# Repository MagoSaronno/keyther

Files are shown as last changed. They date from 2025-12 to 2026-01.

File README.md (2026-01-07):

# Keyther Keyboard
The Keyther Keyboard represents an attempt at perfecting the already great [Cantor Classic](https://github.com/diepala/cantor "The original project").  The name comes from the combination of the substantives **Keyboard** and **Ethernet**, due to the use of an RJ45 socket. 

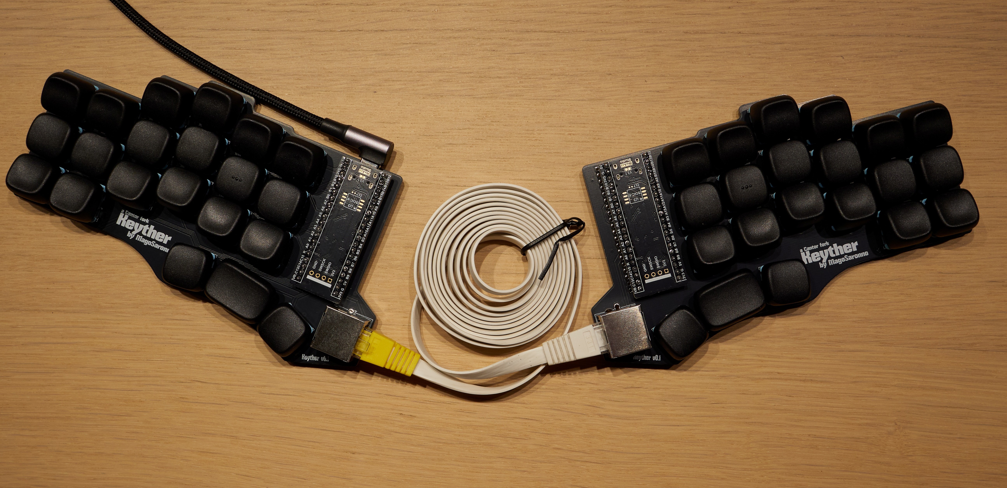
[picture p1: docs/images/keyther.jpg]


*Special thanks to both [diepala](https://github.com/diepala "The Cantor Keyboard creator") and [daprice](https://github.com/daprice "The creator of the footprints libraries") for having paved the way for the creation of the Keyther Keyboard.*

### What changes from Cantor

1. The TRRS socket is replaced with the more secure RJ45 (Ethernet) to avoid *critical* integrity issues caused by accidental disconnection or hot-plugging.  Indeed, the Keyther Keyboard supports hot-plugging, as shown in this video:
 <p align="center"> 
   <a href="https://youtu.be/JiO30BsTjEQ">
    Watch the video
  </a>
</p>

2. The design introduces **hot-swappable** Kailh Choc **sockets** and **handedness by pin** (through the addition of a 10k resistor and an added line in the config.h file)
You won't have to desolder all 42 switches to change them and you will be able to connect the keyboard even through the right half.

3. The horizontal space between switches has been *increased*, accommodating larger hands **without** additional modifications to the overall PCB size (expept the space for the RJ45 socket).

### What does not change

The keyther keyboard keeps (*for the most part*) the original concepts that were at the origin of Cantor, which are the diodeless design and the use of an invertible PCB design, to ultimately avoid cuttable costs.

### Why RJ45 instead of USB-C or magnetic pogo pin sockets?

The main reasons to use RJ45 sockets are their easy soldering, their overall diffusion, and the widespread presence of premade cables of different kinds, like coiled, straight, and flat.

Additionally, the number of pins present on the socket allows the possible addition of two optional communication lines between PCBs for whatever use (namely pins 1 and 5).

# Be Aware
The Keyther Keyboard is designed to be used with ***STRAIGHT-THROUGH CABLES***, not the crossover ones.

***Always check the cable type before connecting the two halves***.

## Disclaimer
All the designs and files are provided "AS IS" without any warranty or support.

## Links Index

[Ordering Guide](docs/Ordering_Guide.md)

[Assembly Guide](docs/Assembling_Guide.md)

[Firmware Guide](https://qmk.fm/guide "The default guide for the Cantor Keyboard")

## Quick Guide

### Bill of Materials (BOM)
The required components needed to assemble the keyboard are the following:
| N. | Item | Notes |
|----|---|---|
| 2  | PCB board | |
| 2  | STM32F401CC BlackPill microcontrollers | *on [AliExpress](https://it.aliexpress.com/item/1005005953179540.html?)* |
| 4  | 20 pin stripes | *usually included with the Blackpill* |
| 42 | Kailh Choc ***v1*** switches | *namely the Kailh PG1350* |
| 42 | Kailh Choc hot-swap sockets | |
| 42 | Kailh Choc ***v1*** compatible keycaps | |
| 2  | RJ45 sockets (RJHSE type, e.g., the [RJHSE-XM80](https://docs.rs-online.com/b456/A700000007566767.pdf "The technical drawing of the socket"))| *on [AliExpress](https://it.aliexpress.com/item/1005007661898327.html?)* |
| 1  | Straight-through Ethernet cable | *flat ones seem to be more flexible and less annoying when using the keyboard* |
| 1  | USB-C cable compatible with your computer | |

### Ordering the PCB
To order the PCB, you will need the Gerber files present in the [Release section](https://github.com/MagoSaronno/keyther/releases). Then, you can either compare the prices on [PCBShopper](https://pcbshopper.com/ "A price comparison site for printed PCBs") by choosing a dimension of 150x90mm or upload them directly to the PCB manufacturer's website of choice.

You can refer to the [Ordering Tutorial](docs/Ordering_Guide.md) page which provides a step-by-step guide on the ordering procedure.

> I personally prototyped my PCBs using JLCPCB, primarily due to lower prices. However, these may vary depending on your customs policies and regional shipping rates.

### Firmware
> It is preferable to flash and check the microcontroller for defects before assembling the keyboard.

The Keyther Keyboard uses the [QMK Firmware](https://qmk.fm/), specifically the same as the Cantor Keyboard. You can easily follow the [guide](https://qmk.fm/guide "The default guide for the Cantor Keyboard") on the QMK website to *customise* and *compile* the firmware.

To add **language-specific characters** (such as *accented* or *umlaut* vowels) you can follow this [additional guide](Language-Specific_Keymap.md).

Unfortunately, at this time, to add the handedness feature to your keyboard you will need to use the [QMK source](https://docs.qmk.fm/newbs "The guide to use the source"), and, before compiling, add to the cantor's config.h file the line:

`#define SPLIT_HAND_PIN B12`

### Enter Bootloader Mode
To flash the firmware onto the microcontroller you will need to set it in bootloader mode first:
- Press and hold the BOOT0 button.
- Press and release the NRST button.
- Release the BOOT0 button.

Now you will be able to flash the firmware and check if the microcontroller works properly.

> Once the first flash has been done successfully you will be able to enter bootloader mode just by plugging in one half of the keyboard **while** holding down the top-left or top-right (*whether it is the left or right keyboard half*).

### Assemble the keyboard
To assemble your Keyther Keyboard you will need a soldering iron and tin of your choice. You can also follow the [Assembly Guide](docs/Assembling_Guide.md).

### Printing the Keyther cases
To 3D print the cases to protect the bottom of your keyboard halves you will need to download the *.stl* files present in the [case folder](https://github.com/MagoSaronno/keyther/tree/main/case) of this repository and slice them with the appropriate software.

In case you wish to modify the designs, you can download the *.step* files in the [step folder](https://github.com/MagoSaronno/keyther/tree/main/case/step).
I've personally succeded in printing them using generic PLA with a layer height of 0.2mm and no supports.

## Feedback
You can fill out [this form](https://forms.gle/tCP48DNiQqiqbWwy6 "Leave here your much appreciated feedback") to let me know of any potential improvements or issues with the project. 

### Have fun!

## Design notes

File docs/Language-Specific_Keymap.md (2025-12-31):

# Using a language-specific keyboard layout

Selecting a different keyboard layout instead of the default international US in the QMK Configurator is quite simple, even though not immediate.

- Go to the [QMK Configurator](https://config.qmk.fm/#/cantor/LAYOUT_split_3x6_3 "The page with the Cantor already selected") and choose a keymap name for the keymap you are going to create;

- Click and open the **Settings** menu in the top-right area of the page;

- Select from the **HOST KEYBOARD LAYOUT** drop-down list your preferred language layout.

 <p align="center"> 
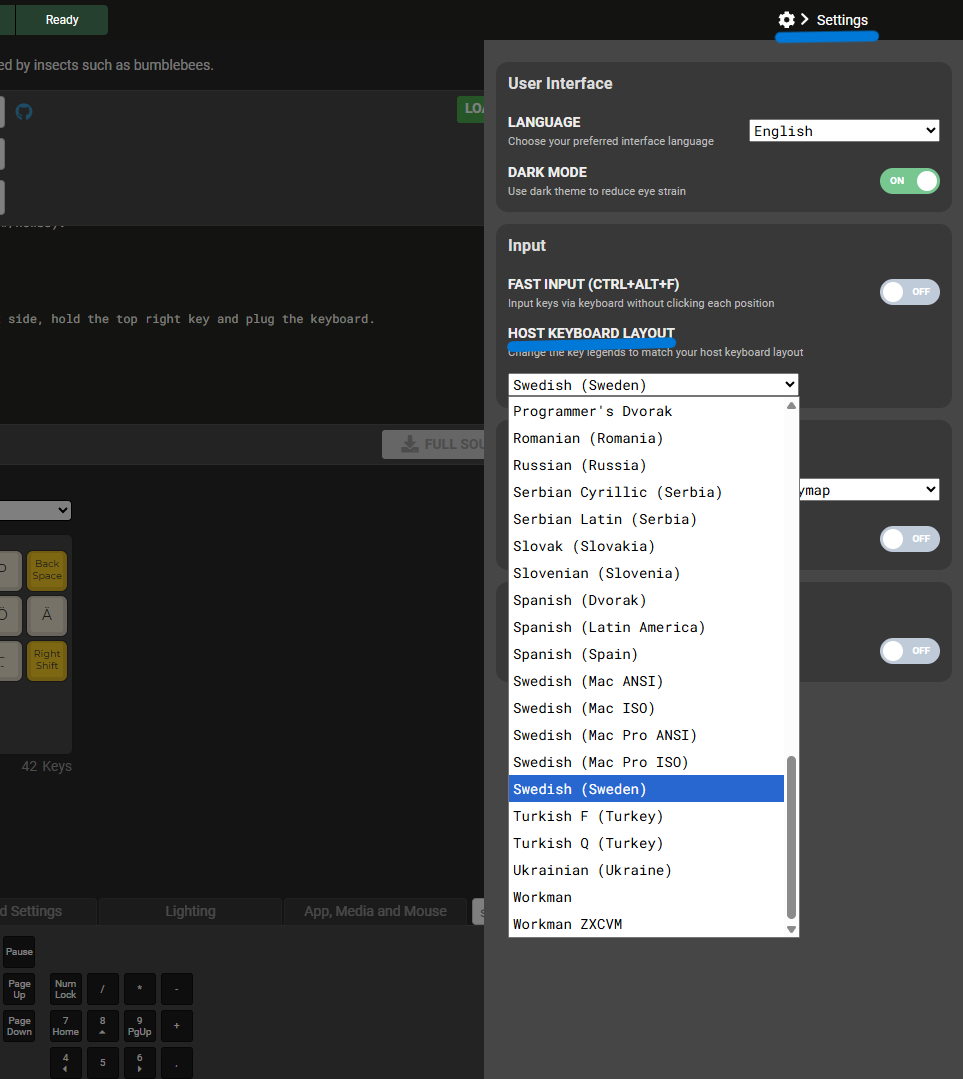
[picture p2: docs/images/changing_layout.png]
    
</p>

Now the *reference keyboard* on the very bottom of the page should show the keyboard layout of your language of choice.  You can now customise your Keyther keyboard layout and add layers to it.

To download the firmware you should first ***compile*** the keymap and then ***download*** it using the designated buttons.  From this point onwards, continue to follow the [guide](https://docs.qmk.fm/configurator_step_by_step "Continue here") on the QMK website.

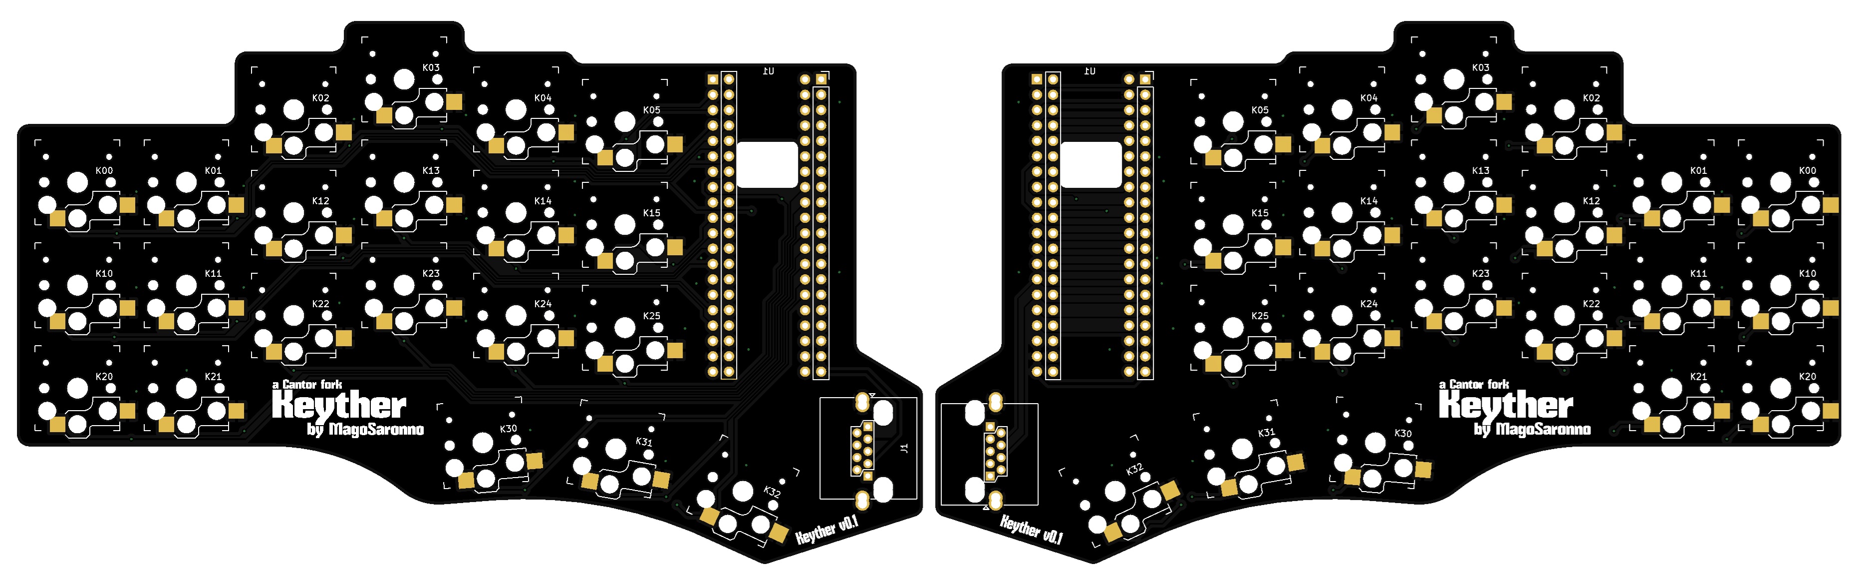
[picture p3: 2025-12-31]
docs/images/PCB_Preview.jpg

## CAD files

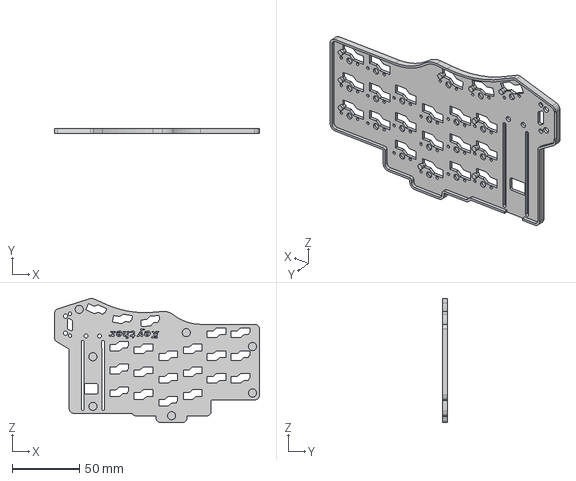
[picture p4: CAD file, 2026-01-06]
case/step/Keyther Mk. I Right Case.step
152.9 x 3.70 x 92.8 mm

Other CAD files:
case/step/Keyther Mk. I Left Case.step
case/Keyther Mk. I Left Case.stl
case/Keyther Mk. I Right Case.stl

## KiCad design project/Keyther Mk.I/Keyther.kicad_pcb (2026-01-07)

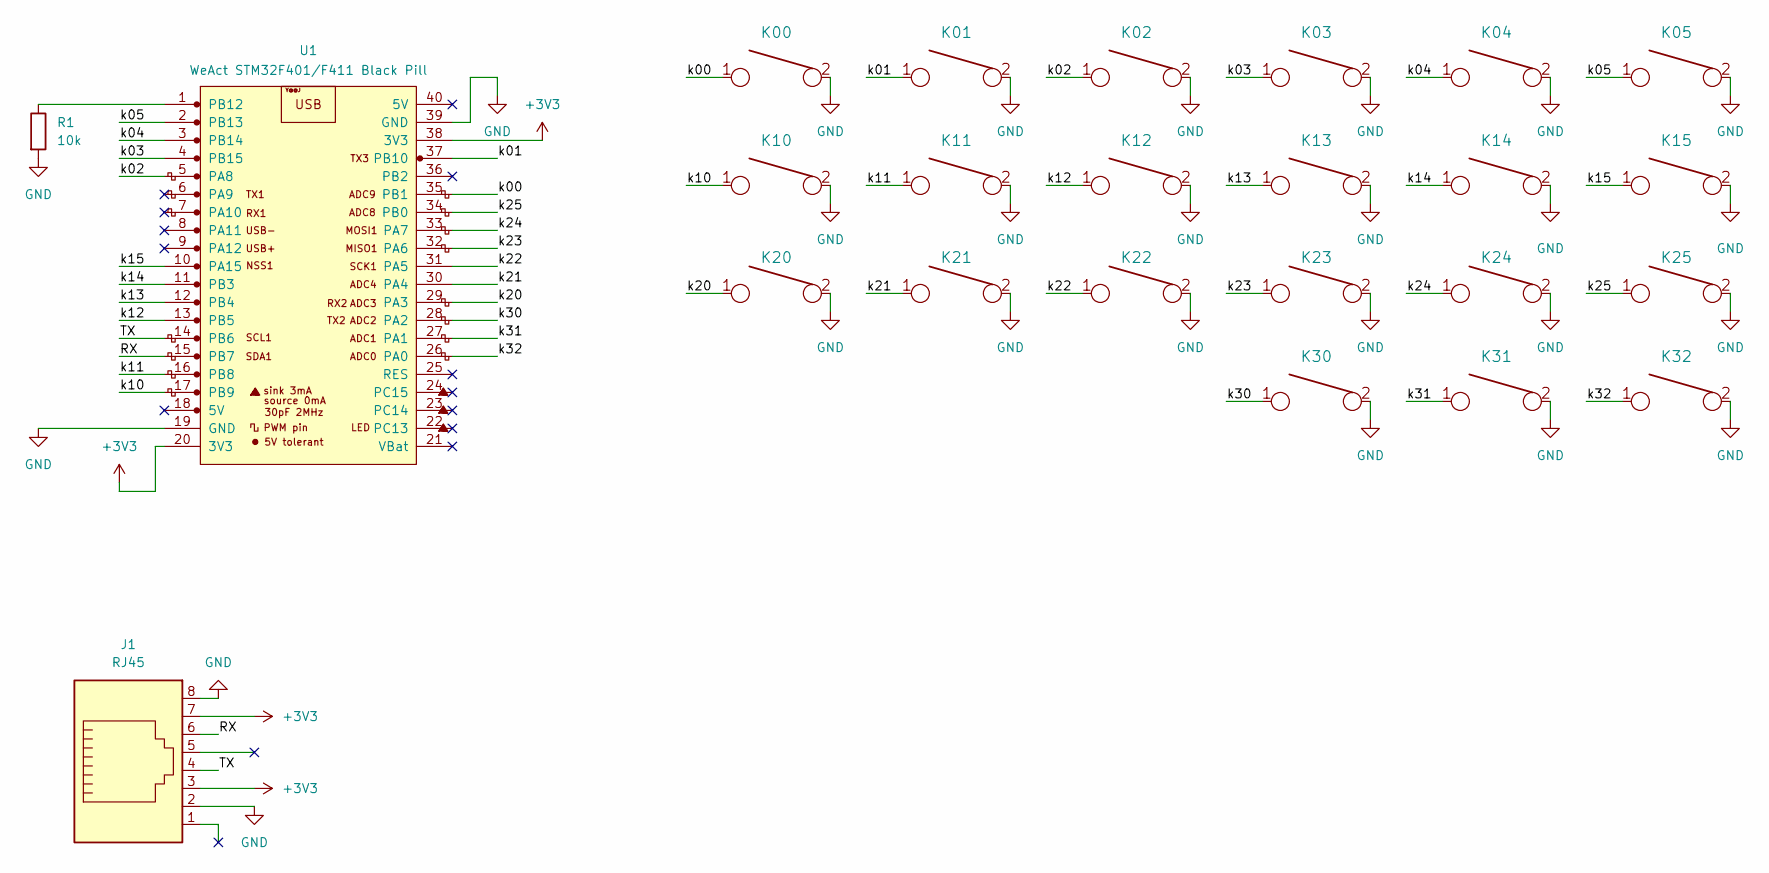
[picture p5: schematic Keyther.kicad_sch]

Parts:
J1: RJ45; RJ45_Amphenol_RJHSE5380
K00, K01, K02, K03, K04, K05, K10, K11, K12, K13, K14, K15, K20, K21, K22, K23, K24, K25, K30, K31, K32: KEYSW; Kailh_socket_PG1350_reversible
R1: 10k; R_Axial_DIN0207_L6.3mm_D2.5mm_P10.16mm_Horizontal
U1: YAAJ_WeAct_BlackPill_Part_Like; YAAJ_BlackPill_2

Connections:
+3V3: J1.3, J1.7, U1.20 (3V3), U1.38 (3V3)
/RX: J1.6, U1.15 (PB7)
/TX: J1.4, U1.14 (PB6)
/k00: K00.1, U1.35 (PB1)
/k01: K01.1, U1.37 (PB10)
/k02: K02.1, U1.5 (PA8)
/k03: K03.1, U1.4 (PB15)
/k04: K04.1, U1.3 (PB14)
/k05: K05.1, U1.2 (PB13)
/k10: K10.1, U1.17 (PB9)
/k11: K11.1, U1.16 (PB8)
/k12: K12.1, U1.13 (PB5)
/k13: K13.1, U1.12 (PB4)
/k14: K14.1, U1.11 (PB3)
/k15: K15.1, U1.10 (PA15)
/k20: K20.1, U1.29 (PA3)
/k21: K21.1, U1.30 (PA4)
/k22: K22.1, U1.31 (PA5)
/k23: K23.1, U1.32 (PA6)
/k24: K24.1, U1.33 (PA7)
/k25: K25.1, U1.34 (PB0)
/k30: K30.1, U1.28 (PA2)
/k31: K31.1, U1.27 (PA1)
/k32: K32.1, U1.26 (PA0)
GND: J1.2, J1.8, J1.SH, K00.2, K01.2, K02.2, K03.2, K04.2, K05.2, K10.2, K11.2, K12.2, K13.2, K14.2, K15.2, K20.2, K21.2, K22.2, K23.2, K24.2, K25.2, K30.2, K31.2, K32.2, R1.2, U1.19 (GND), U1.39 (GND)
unnamed: R1.1, U1.1 (PB12)

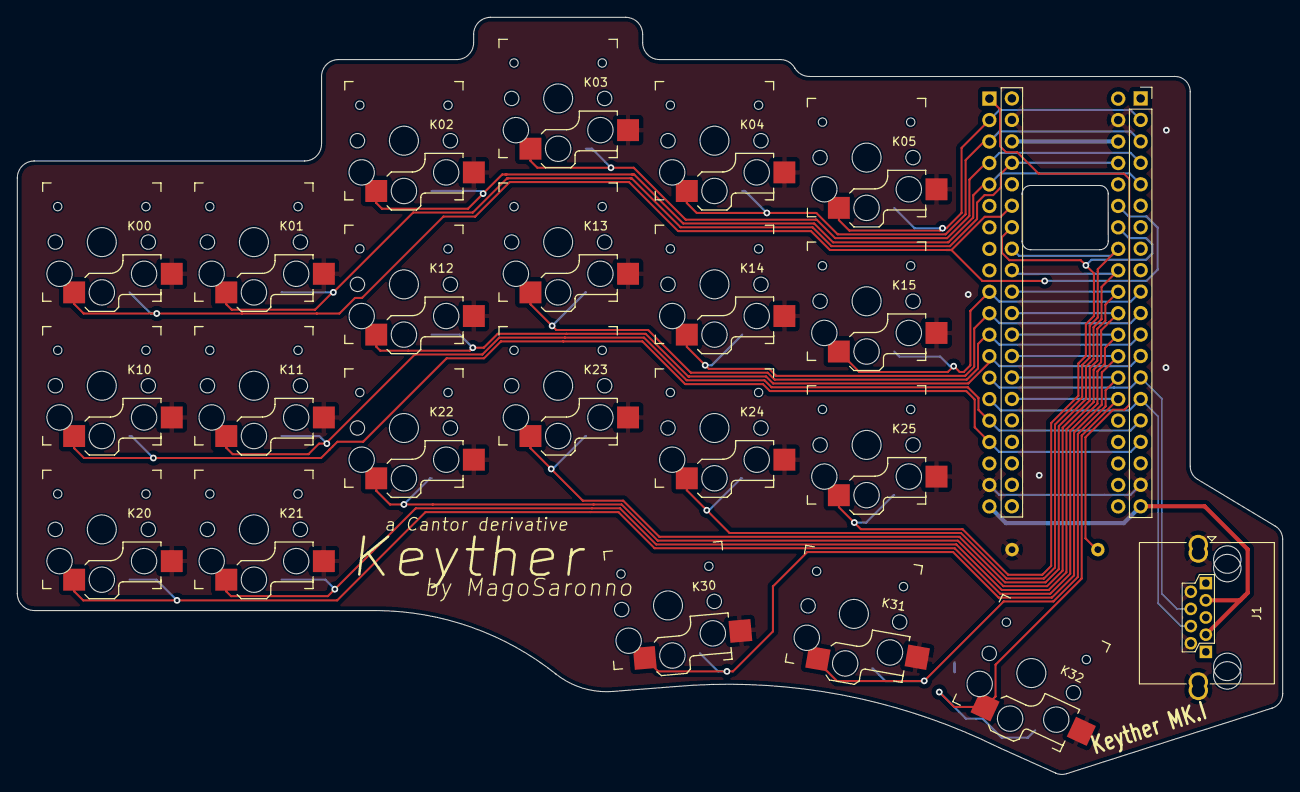
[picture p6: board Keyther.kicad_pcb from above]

Board: 2 copper layers, 149.7 x 89.6 mm, 24 parts (1 on the bottom side), 26 nets.

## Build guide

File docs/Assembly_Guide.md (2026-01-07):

# Keyther assembling guide

1. Prepare all the components and heat up your soldering iron.
   
   > NOTE: It is strongly recommended to flash the firmware to the microcontroller before proceeding to the second step

2. Start by soldering the pin strips to the microcontroller, helping yourself with the PCB to position the shorter pins side as perpendicular to the microcontroller as possible.

<p align="center">
    
</p>

3. Place the PCB with the **bottom side** facing up and solder all the hot-swap sockets as shown in the video below: 

 <p align="center"> 
   <a href="https://youtu.be/L0AAVJCXs2I">
    Watch the video
  </a>
</p>

- tin one of the two PCB pads with a moderate amount of solder;
   
- place the socket in the correct position;
   
- place the soldering iron tip inside the socket contact above the tinned pad and press down until the socket is properly soldered to the pad;
   
- solder the other socket contact.

> I suggest starting to solder the right sockets pad from the side opposite to your dominant hand. Then, rotate the board by 180° and solder the other pads. 

<p align="center">
    
</p>

4- Place the microcontroller underneath the PCB by inserting the pins as shown in the image below. Then, solder it to the board and trim the pins.

<p align="center">
    
</p>

5- Place the RJ45 socket underneath the PCB in the correct holes and solder it to the board.

<p align="center">
    
</p>

6- Solder a 10k resistor in the holes only on the right half of the keyboard to allow automatic handedness (it will enable you to connect the keyboard from the right half instead than only from the left one).

6- Insert the switches in their sockets and add the keycaps.

7- Enjoy your Keyther!

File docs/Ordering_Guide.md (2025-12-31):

# Ordering guide (e.g. JLCPCB)

To order the PCB from most of PCB manufacturers' websites you will first need to download the latest Gerber file from the [releases page](https://github.com/MagoSaronno/keyther/releases), which are provided already as a .zip archive.

You will then need to upload this archive to your preferred manufacurer's website (or the cheapest one you can find using the previously mentioned [website](https://pcbshopper.com/ "A price comparison website for printed PCBs"))

 <p align="center">
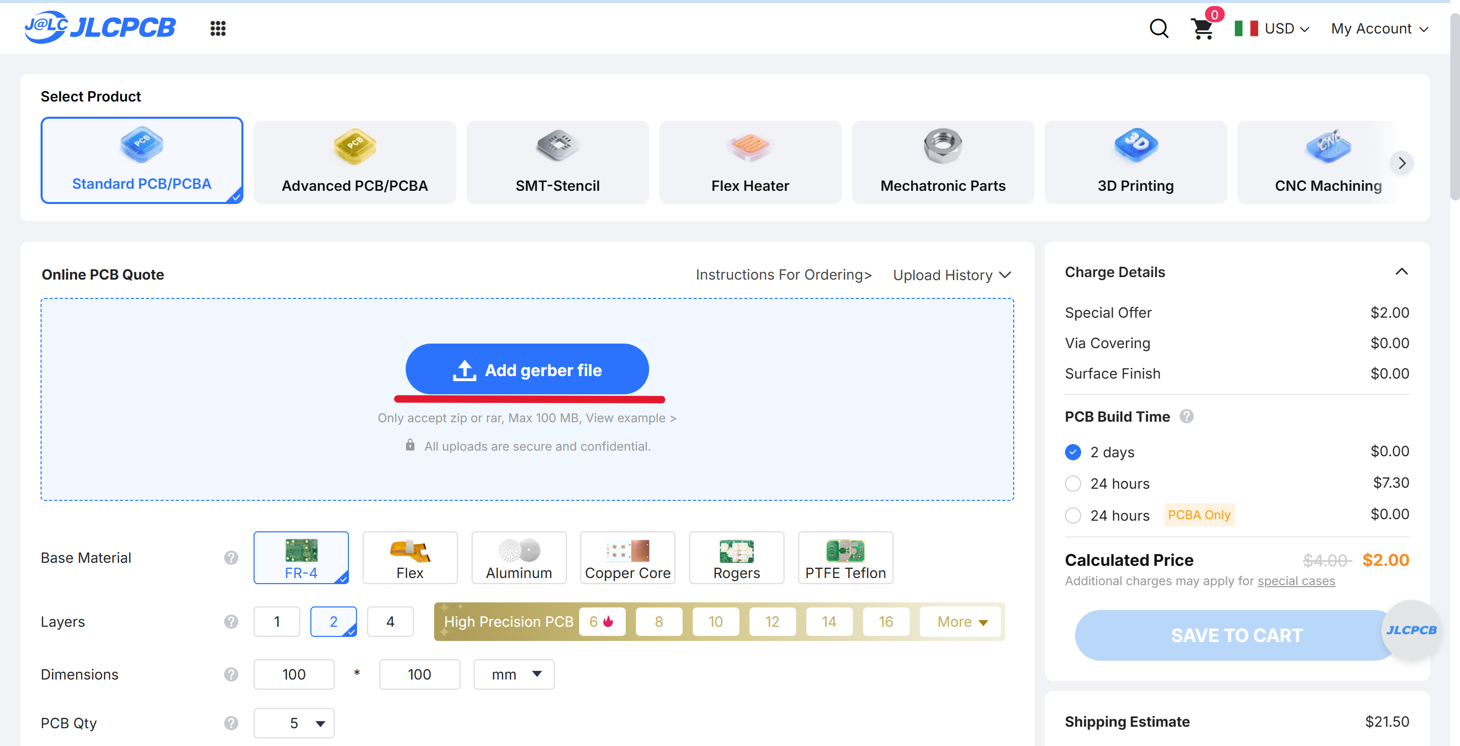
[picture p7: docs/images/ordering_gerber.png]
    
</p>

Once uploaded the only thing you might consider modifying is the colour of both the PCB itself and *silkscreen* (the text and markings on the PCB).  As mentioned previously, you might also want to choose **LeadFree HASL**, *especially if you do not have a fume extractor*.

 <p align="center">
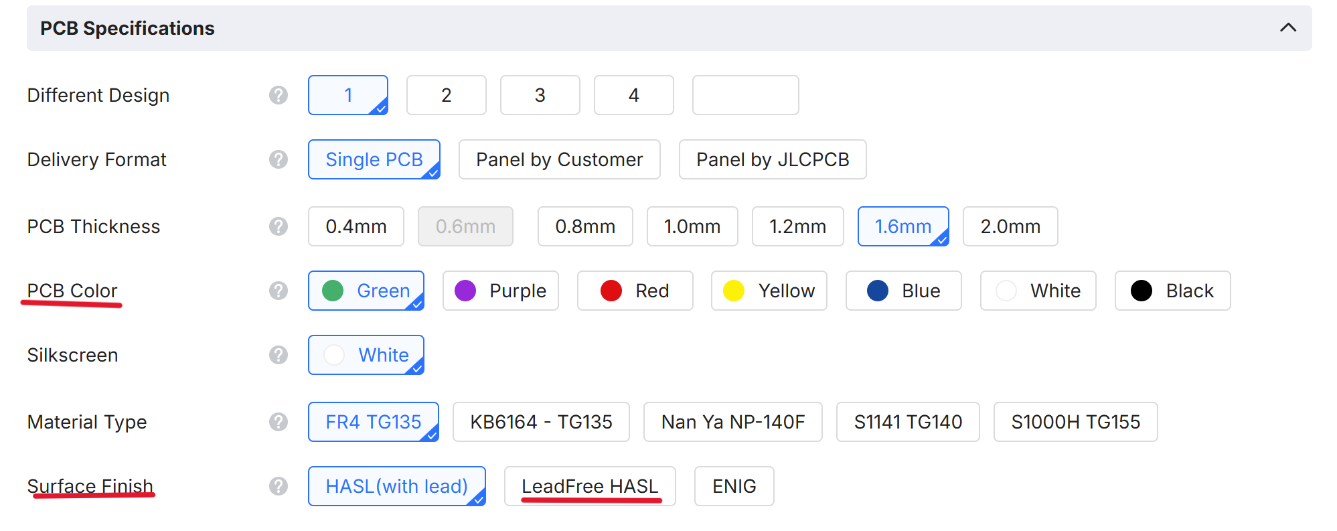
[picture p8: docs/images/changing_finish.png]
    
</p>

You can then proceed by adding the order to your cart and filling your payment and shipping details

***Do not forget to double-check the shipping method, because some major websites tend to change them without warning***

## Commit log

2025-12-31 Update Assembly
2026-01-06 Added 3D printable case files and step for modding
    [Keyther Mk. I Left Case.step, Keyther Mk. I Left Case.stl, Keyther Mk. I Right Case.step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]
2026-01-07 Added updated version project files
    [Keyther.kicad_pcb, Keyther.kicad_sch]
2026-01-07 Updated Assembly_Guide.md to accomodate Mk. I design
